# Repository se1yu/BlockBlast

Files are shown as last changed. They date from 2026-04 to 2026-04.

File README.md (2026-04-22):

# BlockBlast! 
- Demo Link: https://youtu.be/8z5zvf6NJ1U?si=ciNaijVOC2jGjhIF

Using knowledge from ECE 319H at UT Austin (Intro to Embedded Systems) to build a custom video game console and to program Block Blast from scratch. 

Block Blast is a puzzle game I implemented for a MSPM0G3507 microcontroller, displayed on a 128×160 ST7735 Liquid Crystal Display (LCD) screen. The player is presented with an 8×8 grid and a tray of three randomly selected blocks. Using a joystick and four external buttons, the player picks up blocks from the tray, moves them around the grid, and drops them into position. When an entire row or column of the grid becomes filled, it clears and the player earns points. The game ends when any remaining block in the tray has no valid position anywhere on the board. The game supports English and Spanish, tracks a persistent high score across rounds, and features four distinct sound effects triggered by gameplay events.
# Images






--------

# System Architecture
There are two ISRs running concurrently:
Armed with TimerG12_IntArm(80000000/30, 2), which fires an interrupt every 30ms. It does three things each tick:
- Calls JoyStick_In(&JoyX, &JoyY) — which internally triggers ADC_InDual (analog-to-digital-convertor) on ADC1 channels 4 and 6 (PB17 and PB19), sampling both joystick axes simultaneously via a dual-channel 12-bit ADC conversion. According to the Nyquist Theorem, an input should be sampled at a frequency at least twice the maximum input frequency. 30Hz (30 times a second) sampling is well above the maximum frequency a human wrist can move a joystick!
- Calls Switch_In() — reads the four external buttons wired to PA24–PA27, returning a 4-bit value where each bit represents one directional button that is currently being pressed (right/down/left/up). 
- Stores results in the global variables JoyX, JoyY, and sw_status for the main program to access these external hardware updates.

Regarding Audio, we have the SysTick_Handler — Audio DAC at 11 kHz:
Armed with SysTick_IntArm(80000000/11000, 0), this fires every ~90µs and drives the 5-bit binary-weighted DAC on PB0–PB4. It maintains three global variables: pointer to sound array(values to be played to output sound), arrayCount (total # of bytes per sound array), and arrayIndex (current position). Each tick it outputs pointer[arrayIndex] to DAC5_Out() and increments the index. When the array is exhausted it disables the interrupt. Sound is started by calling Sound_Start(pt, count) which resets the index and re-enables the interrupt. This ISR runs at higher priority (0) than the game timer (2) so audio never stutters during gameplay.

# ADC & Joystick
JoyStick_Init() calls ADC_InitDual(ADC1, 4, 6, ADCVREF_VDDA), configuring ADC1 to sequentially sample two channels in one software trigger: channel 4 (PB17, horizontal) and channel 6 (PB19, vertical). ADC_InDual triggers the conversion and "busy-waits" for both results, returning values 0–4095 for each axis. The neutral position is approximately 2048. In Game_Tick, the bounding numbers of 1000 and 3000 define deflection zones — below 1000 means pushed one way, above 3000 means the other. The joystick counts as two slide potentiometers sampled periodically by the ADC at 30 Hz inside the timer ISR.

# Switches/Buttons
Switch_Init() configures PA24–PA27 as digital inputs with PINCM = 0x40081 (input enable + pull-up). Switch_In() reads GPIOA->DIN31_0, masks bits 24–27, and right-shifts by 24 to produce a clean 4-bit value. These are four external buttons wired:
- Bit 0 = right (select / confirm)
- Bit 1 = down (place block)
- Bit 2 = left (back / cancel, requires ~1 second hold on game screen to go backwards)
- Bit 3 = up (pick up block / cancel pickup)

# Sound
Four gameplay sounds are defined in sounds.h as const uint8_t arrays of 5-bit DAC samples recorded at 11 kHz:
- Block_Pickup() — plays when the player picks up a block from the tray
- Block_Place() — plays on successful block placement
- Block_Reject() — plays when a drop is attempted in an invalid position
- Block_Clear() — plays when one or more rows or columns are cleared
Each calls Sound_Start(array, count) which loads the pointer/counter globals and enables the SysTick interrupt. The DAC is a 5-bit R-2R ladder on PB0–PB4, giving 32 voltage levels from 0 to 3.3V.

# Sprites & Graphics
All sprites I drew in Microsoft Paint are stored as const uint16_t arrays in images.h in RGB565 format (16 bit). ST7735_DrawBitmap(x, y, ptr, w, h) renders them with y as the bottom pixel edge. The active sprites in gameplay are:
- Home (128×160) — the menu/title screen background
- grid (128×160) — the full game screen including the 8×8 grid and tray area background
- single (12×12) — 1×1 cell
- miniwide (24×12) — 2×1 cells
- minitall (12×24) — 1×2 cells
- minisquare (24×24) — 2×2 cells
- wide (36×12) — 3×1 cells
- tall (12×36) — 1×3 cells
- square (36×36) — 3×3 cells
Moving sprite: The held block moves across the grid in 12px increments (one cell) responding to joystick deflection. On each move, ST7735_DrawBitmap(grid) redraws the background, all filled cells are repainted as solid 10×10px colored squares inside each 12×12 cell, the tray is redrawn, and finally the held block is drawn at its new position.

# Grid & Game Logic
The grid state is a uint8_t grid_matrix[8][8] where 0 = empty and 1 = filled. Block types are described by a BlockType_t struct containing the sprite pointer, pixel dimensions, and cell footprint. The active tray is traySlotType[3] — indices into allBlockTypes[7] — randomized each respawn using a linear congruential generator from SysTick->VAL at game start for true randomness. Random32() implements a linear congruential generator: M = 1664525*M + 1013904223. RandomType() uses (Random32() >> 24) % 7 — taking bits 31–24 for a cycle length of 2²⁴ rather than the short-cycling low bits. The seed M = SysTick->VAL is set once at Game_Init(), capturing the hardware counter at the moment the player starts the game, ensuring a different block sequence every round.

The canPlace(slot, col, row) checks bounds and scans the footprint against the matrix. stampBlock writes 1s into the matrix. checkAndClearLines() after every placement scans all 8 rows and 8 columns, marks full ones, then zeroes any cell whose row or column was full — handling intersections correctly without double-counting. isGameOver() iterates all available tray blocks and calls canBlockFitAnywhere() which scans every valid grid position; if any available block has zero valid placements, the game ends.

# LEDs 
Three LEDs on PA15–PA17 indicate which tray slot is currently selected. LED_On(data) left-shifts data by 15 to align with the GPIO pins. Only the LED corresponding to traySelection lights up, and it goes dark when that slot's block is picked up or placed.

# Language Support 
All user-facing strings exist in both English and Spanish. A lang variable (0 = English, 1 = Spanish) indexes into parallel string arrays for menu labels, tutorial text, and prompts. The language cycles with the Language menu option and persists through the game session.

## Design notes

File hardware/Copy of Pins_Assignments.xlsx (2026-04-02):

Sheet: Design
J1 | MSPM0 | MSPM0 | J3 | J4 | MSPM0 | MSPM0 | J2
 | 1 | 21 |  |  | 40 | 20
 | 3.3V | 5V |  | DAC5 | PB4[7] | GND
SWITCH | PA25 | GND |  | DAC5 | PB1[7] | PB12
PA9 or PB23 | SW1 | PB19 |  |  | PA28 | PB17
U1_Tx | PA8[4] | PA22[5] | U2_Rx |  | PA31 | PB15[1] | GPIO/Reset to ST7735
SWITCH | PA26 | PB18 | ADC1_5 Slide pot | TExaS scope ADC0_6 | PB20[6] | !RST
LED | PB24 | PA18 |  |  | PB13 | PB8[1] | MOSI to ST7735
SPI1_SCK | PB9[1] | PA24 | SWITCH | U0_TX [2] | PA10[3] | PB7[1] | MISO to ST7735
SWITCH | PA27 | PA17 | LED | U0_RX[2] | PA11[3] | PB6[1] | TFT_CS to ST7735
DAC5 | PB2[7] | SW2 | PA16 or PA18 (LED) | CARD_CS to ST7735 | PA12[1] | PB0[7] | DAC5
DAC5 | PB3[7] | PA15[0] | DAC output | D/C to ST7735 | PA13[1] | PB16
Notes: |  |  |  |  | MSPM0
[0] DAC output, but could be GPIO |  |  |  |  | DAC
[1] ST7735R LCD and SDC (either Adafruit and HiLetGo) with SDC |  |  |  |  | SPI1
[2] Slide pot to PB18 ADC1 channel 5 |  |  |  |  | ADC1
[3] UART0 communication with laptop, serial console window |  |  |  |  | UART0
[4] UART1 transmit output to other computer in Lab 8 |  |  |  |  | UART1
[5] UART2 receive input from other computer in Lab 8 |  |  |  |  | UART2
[6] ADC0 channel 6 analog input for TExaS scope, PB20 |  |  |  |  | ADC0
[7] 5 bit DAC |  |  |  |  | GPIOB
[8] MY LCD

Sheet: Timers
 | base clock | size | prescale
SysTick | 80MHz | 24 bit | none
TimerA0 | 80MHz | 16 bit | 8 bit
TimerA1 | 80MHz | 16 bit | 8 bit
TimerG0 | 40MHz | 16 bit | 8 bit
TimerG12 | 80MHz | 32 bit | none
TimerG6 | 80MHz | 16 bit | 8 bit
TimerG7 | 80MHz | 16 bit | 8 bit
TimerG8 | 40MHz | 16 bit | 8 bit

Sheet: Pins
notes | J5 pins
 | PA0 | PA.0/UART0_TX/I2C0_SDA/TIMA0_C0/TIMA1_FAL | J5 pins
 | PA1 | PA.1/UART0_RX/I2C0_SCL/TIMA0_C1/TIMA2_FAL | J5 pins
 | PA2 | PA.2/TIMG1_C1/SPI0_CS0/ROSC | J5 pins
 | PA3 | PA.3/TIMG1_C0/SPI0_CS1/UART2_CTS/TIMA0_C2/COMP1_OUT/LFXIN | J5 pins
 | PA4 | PA.4/TIMG1_C1/SPI0_POCI/UART2_RTS/TIMA0_C3/LFCLK_IN/LFXOUT | J5 pins
 | PA5 | PA.5/TIMG10_C0/SPI0_PICO/TIMA1_FAL/TIMG0_C0/HFXIN | J5 pins
 | PA6 | PA.6/TIMG10_C1/SPI0_SCK/TIMA0_FAL/TIMG0_C1/HFCLK_IN/ | J5 pins
 | PA7 | PA.7/COMP0_OUT/CLK_OUT/TIMG1_C0/TIMA0_C2/TIMG10_IDX | J5 pins
Duplicated on J4 | PA10 | PA.10/UART0_TX/SPI0_POCI/I2C0_SDA/TIMA1_C0/TIMH0_C0 | J5 pins
Duplicated on J4 | PA11 | PA.11/UART0_RX/SPI0_SCK/I2C0_SCL/TIMA1_C1/COMP0_OUT | J5 pins
Duplicated on J4 | PA12 | PA.12/UART3_CTS/SPI0_SCK/TIMG0_C0/CAN_TX | J5 pins
Duplicated on J4 | PA13 | PA.13/UART3_RTS/SPI0_POCI/UART3_RX/TIMG0_C1/CAN_RX/COMP0_IN2- | J5 pins
 | PA14 | PA.14/UART0_CTS/SPI0_PICO/UART3_TX/TIMH0_C0/CLK_OUT/COMP0_IN2+ | J5 pins
 | PA21 | PA.21/UART2_TX/TIMG10_C0/UART1_CTS/TIMA0_C0/ADC1_7/COMP2_IN1-/VeREF | J5 pins
 | PA23 | PA.23/UART2_TX/SPI0_CS3/TIMA2_C0/TIMG0_C0/UART3_CTS/COMP1_IN1-/VeREF+ | J5 pins
 | PB5 | PB.5/UART1_RX/UART3_RTS/TIMA1_C1 | J5 pins
 | PB10 | PB.10/TIMG0_C0/TIMG1_C0/COMP1_OUT | J5 pins
 | PB11 | PB.11/TIMG0_C1/TIMG1_C1/CLK_OUT | J5 pins
 | PB21 | PB.21/SPI1_POCI/TIMG10_C0/COMP2_IN0+ | J5 pins
 | PB22 | PB.22/SPI1_PICO/TIMG10_C1/COMP2_IN0- | J5 pins
J14 jumper to J1 | PB23 | PB.23/SPI1_SCK/COMP0_OUT/TIMA0_FAL | J5 pins
 | PB25 | PB.25/UART0_CTS/SPI0_CS0/TIMA2_FAL/ADC0_4 | J5 pins
 | PB26 | PB.26/UART0_RTS/SPI0_CS1/TIMA2_C0/COMP1_IN0+ | J5 pins
 | PB27 | PB.27/COMP2_OUT/SPI1_CS1/TIMA2_C1/COMP1_IN0- | J5 pins
QEI pins
 | PA29 | PA.29/I2C1_SCL/UART2_RTS/TIMG10_C0 | QEI pins
 | PA30 | PA.30/I2C1_SDA/UART2_CTS/TIMG10_C1 | QEI pins
 | PB14 | PB.14/SPI1_CS3/SPI1_POCI/SPI0_CS3/TIMH0_C1/TIMG10_IDX | QEI pins
 | J1
 | 3.3V
 | PA25 | PA.25/UART3_RX/SPI1_CS3/TIMH0_C1/TIMA0_C3/ADC0_2/OPA0_IN1+ | J1
 | PA9[5] | PA.9/UART1_RX/SPI0_PICO/UART0_CTS/TIMA0_C1/RTC | J1
 | PA8 | PA.8/UART1_TX/SPI0_CS0/UART0_RTS/TIMA0_C0 | J1
 | PB24 | PB.24/SPI0_CS3/SPI0_CS1/TIMA0_C3/TIMH0_C1/ADC0_5/COMP1_IN1+ | J1
 | PA26 | PA.26/UART3_TX/SPI1_CS0/TIMG1_C0/TIMA0_FAL/ADC0_1/COMP0_IN0+/OPA0_IN0+/GPAMP_IN+/CAN_TX | J1
 | PB9 | PB.9/UART1_RTS/SPI1_SCK/TIMA0_C1 | J1
 | PA27 | PA.27/RTC_OUT/SPI1_CS1/TIMG1_C1/TIMA2_FAL/ADC0_0/COMP0_IN0-/OPA0_IN0-/CAN_RX | J1
 | PB2 | PB.2/UART3_TX/UART2_CTS/I2C1_SCL/TIMA2_C0/UART1_CTS | J1
 | PB3 | PB.3/UART3_RX/UART2_RTS/I2C1_SDA/TIMA2_C1/UART1_RTS | J1
 | J3
 | 5V |  | J3
 | GND |  | J3
 | PB19 | PB.19/COMP2_OUT/SPI0_POCI/TIMG1_C1/UART0_CTS/ADC1_6/COMP2_IN1+/OPA1_IN0+ | J3
 | PA22 | PA.22/UART2_RX/TIMG10_C1/UART1_RTS/TIMA0_C1/CLK_OUT/ADC0_7/GPAMP_OUT/OPA0_OUT | J3
 | PB18 | PB.18/UART2_RX/SPI0_SCK/SPI1_CS2/TIMA1_C1/ADC1_5/COMP1_IN2+ | J3
 | PA18 | PA.18/UART1_RX/SPI1_PICO/I2C1_SDA/TIMA2_C1/BSL_invoke/ADC1_3/OPA1_IN1+/COMP0_IN1+/GPAMP_IN12 | J3
 | PA24 | PA.24/UART2_RX/SPI0_CS2/TIMA2_C1/TIMG0_C1/UART3_RTS/ADC0_3/OPA0_IN1- | J3
 | PA17 | PA.17/UART1_TX/SPI1_SCK/I2C1_SCL/TIMA2_C0/ADC1_2/OPA1_IN1-/COMP0_IN1- | J3
 | PA16[6] | PA.16/COMP2_OUT/SPI1_POCI/I2C1_SDA/TIMA1_C1/ADC1_1/OPA1_OUT | J3
 | PA15 | PA.15/UART0_RTS/SPI1_CS2/I2C1_SCL/TIMA1_C0/TIMG10_IDX/ADC1_0/DAC_OUT | J3
 | J4
 | PB4 | PB.4/UART1_TX/UART3_CTS/TIMA1_C0 | J4
 | PB1 | PB.1/UART0_RX/SPI1_CS3/TIMA1_C1 | J4
 | PA28 | PA.28/UART0_TX/I2C0_SDA/TIMA2_C0/TIMA0_FAL | J4
 | PA31 | PA.31/UART0_RX/I2C0_SCL/TIMA2_C1/TIMH0_C1/CLK_OUT | J4
 | PB20 | PB.20/SPI0_CS2/SPI1_CS0/TIMA0_C2/TIMH0_C0/TIMA1_FAL/ADC0_6/OPA1_IN0- | J4
 | PB13 | PB.13/UART3_RX/TIMA0_C3/TIMH0_C0 | J4
 | PA10 | PA.10/UART0_TX/SPI0_POCI/I2C0_SDA/TIMA1_C0/TIMH0_C0 | J4
 | PA11 | PA.11/UART0_RX/SPI0_SCK/I2C0_SCL/TIMA1_C1/COMP0_OUT | J4
 | PA12 | PA.12/UART3_CTS/SPI0_SCK/TIMG0_C0/CAN_TX | J4
 | PA13 | PA.13/UART3_RTS/SPI0_POCI/UART3_RX/TIMG0_C1/CAN_RX/COMP0_IN2- | J4
 | J2
 | GND |  | J2
 | PB12 | PB.12/UART3_TX/TIMA0_C2/TIMA1_FAL | J2
 | PB17 | PB.17/UART2_TX/SPI0_PICO/SPI1_CS1/TIMA1_C0/ADC1_4/COMP1_IN2- | J2
 | PB15 | PB.15/UART2_TX/SPI1_PICO/UART3_CTS/TIMG1_C0 | J2
 | !RST |  | J2
 | PB8 | PB.8/UART1_CTS/SPI1_PICO/TIMA0_C0/COMP1_OUT | J2
 | PB7 | PB.7/UART1_RX/SPI1_POCI/SPI0_CS2/TIMG10_C1/UART2_RTS | J2
 | PB6 | PB.6/UART1_TX/SPI1_CS0/SPI0_CS1/TIMG10_C0/UART2_CTS | J2
 | PB0 | PB.0/UART0_TX/SPI1_CS2/TIMA1_C0 | J2
 | PB16 | PB.16/UART2_RX/SPI1_SCK/UART3_RTS/TIMG1_C1 | J2

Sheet: J5
M0G350 Header | A0 | B25 | B22 | B11 | B5 | A1 | A14 | A6 | A4 | A2 | GND | GND | A11
M0G350 Header | B27 | B26 | B23 | B21 | B10 | A23 | A21 | A7 | A5 | A3 | A12 | A13 | A10

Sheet: PINCM
PINCM | Pin | Mode2 | Mode3 | Mode4 | Mode5 | Mode6 | Mode7 | Mode8 | Mode9
1 | PA0 | UART0_TX | I2C0_SDA | TIMA0_C0 | TIMA_FAL1 | TIMG8_C1 | FCC_IN
2 | PA1 | UART0_RX | I2C0_SCL | TIMA0_C1 | TIMA_FAL2 | TIMG8_IDX | TIMG8_C0
7 | PA2 | TIMG8_C1 | SPI0_CS0 | TIMG7_C1 | SPI1_CS0
8 | PA3 | TIMG8_C0 | SPI0_CS1 | UART2_CTS | TIMA0_C2 | COMP1_OUT | TIMG7_C0 | TIMA0_C1 | I2C1_SDA
9 | PA4 | TIMG8_C1 | SPI0_POCI | UART2_RTS | TIMA0_C3 | LFCLK_IN | TIMG7_C1 | TIMA0_C1N | I2C1_SCL
10 | PA5 | TIMG8_C0 | SPI0_PICO | TIMA_FAL1 | TIMG0_C0 | TIMG6_C0 | FCC_IN
11 | PA6 | TIMG8_C1 | SPI0_SCK | TIMA_FAL0 | TIMG0_C1 | HFCLK_IN | TIMG6_C1 | TIMA0_C2N
14 | PA7 | COMP0_OUT | CLK_OUT | TIMG8_C0 | TIMA0_C2 | TIMG8_IDX | TIMG7_C1 | TIMA0_C1
19 | PA8 | UART1_TX | SPI0_CS0 | UART0_RTS | TIMA0_C0 | TIMA1_C0N
20 | PA9 | UART1_RX | SPI0_PICO | UART0_CTS | TIMA0_C1 | RTC_OUT | TIMA0_C0N | TIMA1_C1N | CLK_OUT
21 | PA10 | UART0_TX | SPI0_POCI | I2C0_SDA | TIMA1_C0 | TIMG12_C0 | TIMA0_C2 | I2C1_SDA | CLK_OUT
22 | PA11 | UART0_RX | SPI0_SCK | I2C0_SCL | TIMA1_C1 | COMP0_OUT | TIMA0_C2N | I2C1_SCL
34 | PA12 | UART3_CTS | SPI0_SCK | TIMG0_C0 | CAN_TX | TIMA0_C3 | FCC_IN
35 | PA13 | UART3_RTS | SPI0_POCI | UART3_RX | TIMG0_C1 | CAN_RX | TIMA0_C3N
36 | PA14 | UART0_CTS | SPI0_PICO | UART3_TX | TIMG12_C0 | CLK_OUT
37 | PA15 | UART0_RTS | SPI1_CS2 | I2C1_SCL | TIMA1_C0 | TIMG8_IDX | TIMA1_C0N | TIMA0_C2
38 | PA16 | COMP2_OUT | SPI1_POCI | I2C1_SDA | TIMA1_C1 | TIMA1_C1N | TIMA0_C2N | FCC_IN
39 | PA17 | UART1_TX | SPI1_SCK | I2C1_SCL | TIMA0_C3 | TIMG7_C0 | TIMA1_C0
40 | PA18 | UART1_RX | SPI1_PICO | I2C1_SDA | TIMA0_C3N | TIMG7_C1 | TIMA1_C1
41 | PA19 | SWDIO
42 | PA20 | SWCLK
46 | PA21 | UART2_TX | TIMG8_C0 | UART1_CTS | TIMA0_C0 | TIMG6_C0
47 | PA22 | UART2_RX | TIMG8_C1 | UART1_RTS | TIMA0_C1 | CLK_OUT | TIMA0_C0N | TIMG6_C1
53 | PA23 | UART2_TX | SPI0_CS3 | TIMA0_C3 | TIMG0_C0 | UART3_CTS | TIMG7_C0 | TIMG8_C0
54 | PA24 | UART2_RX | SPI0_CS2 | TIMA0_C3N | TIMG0_C1 | UART3_RTS | TIMG7_C1 | TIMA1_C1
55 | PA25 | UART3_RX | SPI1_CS3 | TIMG12_C1 | TIMA0_C3 | TIMA0_C1N
59 | PA26 | UART3_TX | SPI1_CS0 | TIMG8_C0 | TIMA_FAL0 | CAN_TX | TIMG7_C0
60 | PA27 | RTC_OUT | SPI1_CS1 | TIMG8_C1 | TIMA_FAL2 | CAN_RX | TIMG7_C1
3 | PA28 | UART0_TX | I2C0_SDA | TIMA0_C3 | TIMA_FAL0 | TIMG7_C0 | TIMA1_C0
4 | PA29 | I2C1_SCL | UART2_RTS | TIMG8_C0 | TIMG6_C0
5 | PA30 | I2C1_SDA | UART2_CTS | TIMG8_C1 | TIMG6_C1
6 | PA31 | UART0_RX | I2C0_SCL | TIMA0_C3N | TIMG12_C1 | CLK_OUT | TIMG7_C1 | TIMA1_C1
12 | PB0 | UART0_TX | SPI1_CS2 | TIMA1_C0 | TIMA0_C2
13 | PB1 | UART0_RX | SPI1_CS3 | TIMA1_C1 | TIMA0_C2N
15 | PB2 | UART3_TX | UART2_CTS | I2C1_SCL | TIMA0_C3 | UART1_CTS | TIMG6_C0 | TIMA1_C0
16 | PB3 | UART3_RX | UART2_RTS | I2C1_SDA | TIMA0_C3N | UART1_RTS | TIMG6_C1 | TIMA1_C1
17 | PB4 | UART1_TX | UART3_CTS | TIMA1_C0 | TIMA0_C2 | TIMA1_C0N
18 | PB5 | UART1_RX | UART3_RTS | TIMA1_C1 | TIMA0_C2N | TIMA1_C1N
23 | PB6 | UART1_TX | SPI1_CS0 | SPI0_CS1 | TIMG8_C0 | UART2_CTS | TIMG6_C0 | TIMA1_C0N
24 | PB7 | UART1_RX | SPI1_POCI | SPI0_CS2 | TIMG8_C1 | UART2_RTS | TIMG6_C1 | TIMA1_C1N
25 | PB8 | UART1_CTS | SPI1_PICO | TIMA0_C0 | COMP1_OUT
26 | PB9 | UART1_RTS | SPI1_SCK | TIMA0_C1 | TIMA0_C0N
27 | PB10 | TIMG0_C0 | TIMG8_C0 | COMP1_OUT | TIMG6_C0
28 | PB11 | TIMG0_C1 | TIMG8_C1 | CLK_OUT | TIMG6_C1
29 | PB12 | UART3_TX | TIMA0_C2 | TIMA_FAL1 | TIMA0_C1
30 | PB13 | UART3_RX | TIMA0_C3 | TIMG12_C0 | TIMA0_C1N
31 | PB14 | SPI1_CS3 | SPI1_POCI | SPI0_CS3 | TIMG12_C1 | TIMG8_IDX | TIMA0_C0
32 | PB15 | UART2_TX | SPI1_PICO | UART3_CTS | TIMG8_C0 | TIMG7_C0
33 | PB16 | UART2_RX | SPI1_SCK | UART3_RTS | TIMG8_C1 | TIMG7_C1
43 | PB17 | UART2_TX | SPI0_PICO | SPI1_CS1 | TIMA1_C0 | TIMA0_C2
44 | PB18 | UART2_RX | SPI0_SCK | SPI1_CS2 | TIMA1_C1 | TIMA0_C2N
45 | PB19 | COMP2_OUT | SPI0_POCI | TIMG8_C1 | UART0_CTS | TIMG7_C1
48 | PB20 | SPI0_CS2 | SPI1_CS0 | TIMA0_C2 | TIMG12_C0 | TIMA_FAL1 | TIMA0_C1 | TIMA1_C1N
49 | PB21 | SPI1_POCI | TIMG8_C0
50 | PB22 | SPI1_PICO | TIMG8_C1
51 | PB23 | SPI1_SCK | COMP0_OUT | TIMA_FAL0
52 | PB24 | SPI0_CS3 | SPI0_CS1 | TIMA0_C3 | TIMG12_C1 | TIMA0_C1N | TIMA1_C0N
56 | PB25 | UART0_CTS | SPI0_CS0 | TIMA_FAL2
57 | PB26 | UART0_RTS | SPI0_CS1 | TIMA0_C3 | TIMG6_C0 | TIMA1_C0
58 | PB27 | COMP2_OUT | SPI1_CS1 | TIMA0_C3N | TIMG6_C1 | TIMA1_C1

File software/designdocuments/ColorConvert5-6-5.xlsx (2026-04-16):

red | green | blue | 565
0 | 255 | 120 | 0x7FE0 | 0x7FE0, // 0, 255, 120

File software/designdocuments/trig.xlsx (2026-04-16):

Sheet: 64
 | 2 |  | 64
angle | vx | vy | ix | iy
0 | 2 | 0 | 128 | 0
0.09817477042 | 1.990369453 | 0.1960342807 | 127 | 13
0.1963495408 | 1.961570561 | 0.390180644 | 126 | 25
0.2945243113 | 1.913880671 | 0.5805693545 | 122 | 37
0.3926990817 | 1.847759065 | 0.7653668647 | 118 | 49
0.4908738521 | 1.763842529 | 0.9427934737 | 113 | 60
0.5890486225 | 1.662939225 | 1.111140466 | 106 | 71
0.687223393 | 1.546020907 | 1.268786568 | 99 | 81
0.7853981634 | 1.414213562 | 1.414213562 | 91 | 91
0.8835729338 | 1.268786568 | 1.546020907 | 81 | 99
0.9817477042 | 1.111140466 | 1.662939225 | 71 | 106
1.079922475 | 0.9427934737 | 1.763842529 | 60 | 113
1.178097245 | 0.7653668647 | 1.847759065 | 49 | 118
1.276272016 | 0.5805693545 | 1.913880671 | 37 | 122
1.374446786 | 0.390180644 | 1.961570561 | 25 | 126
1.472621556 | 0.1960342807 | 1.990369453 | 13 | 127
1.570796327 | -7.656635742e-16 | 2 | 0 | 128
1.668971097 | -0.1960342807 | 1.990369453 | -13 | 127
1.767145868 | -0.390180644 | 1.961570561 | -25 | 126
1.865320638 | -0.5805693545 | 1.913880671 | -37 | 122
1.963495408 | -0.7653668647 | 1.847759065 | -49 | 118
2.061670179 | -0.9427934737 | 1.763842529 | -60 | 113
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

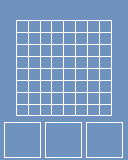
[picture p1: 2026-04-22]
software/images/Blocks/grid.bmp

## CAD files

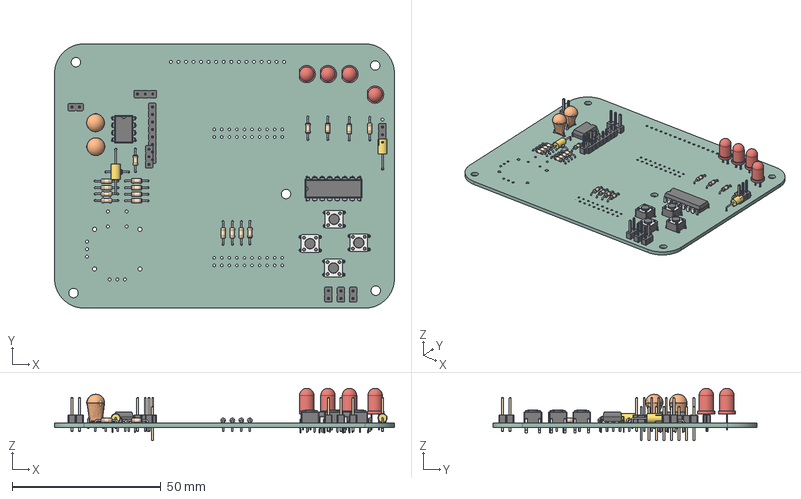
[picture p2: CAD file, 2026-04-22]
hardware/v1.0.0/model.step
114.3 x 88.9 x 17.6 mm
R_Axial_DIN0204_L3.6mm_D1.6mm_P7.62mm_Horizontal x 18
PinHeader_1x03_P2.54mm_Vertical x 3
DIP-8_W7.62mm
SW_PUSH_6mm x 4
PinHeader_1x02_P2.54mm_Vertical x 4
C_Axial_L5.1mm_D3.1mm_P15.00mm_Horizontal x 2
PinHeader_1x08_P2.54mm_Vertical
CP_Radial_Tantal_D6.0mm_P5.00mm x 2
DIP-16_W7.62mm
LED_D5.0mm x 4
jc224364_PCB

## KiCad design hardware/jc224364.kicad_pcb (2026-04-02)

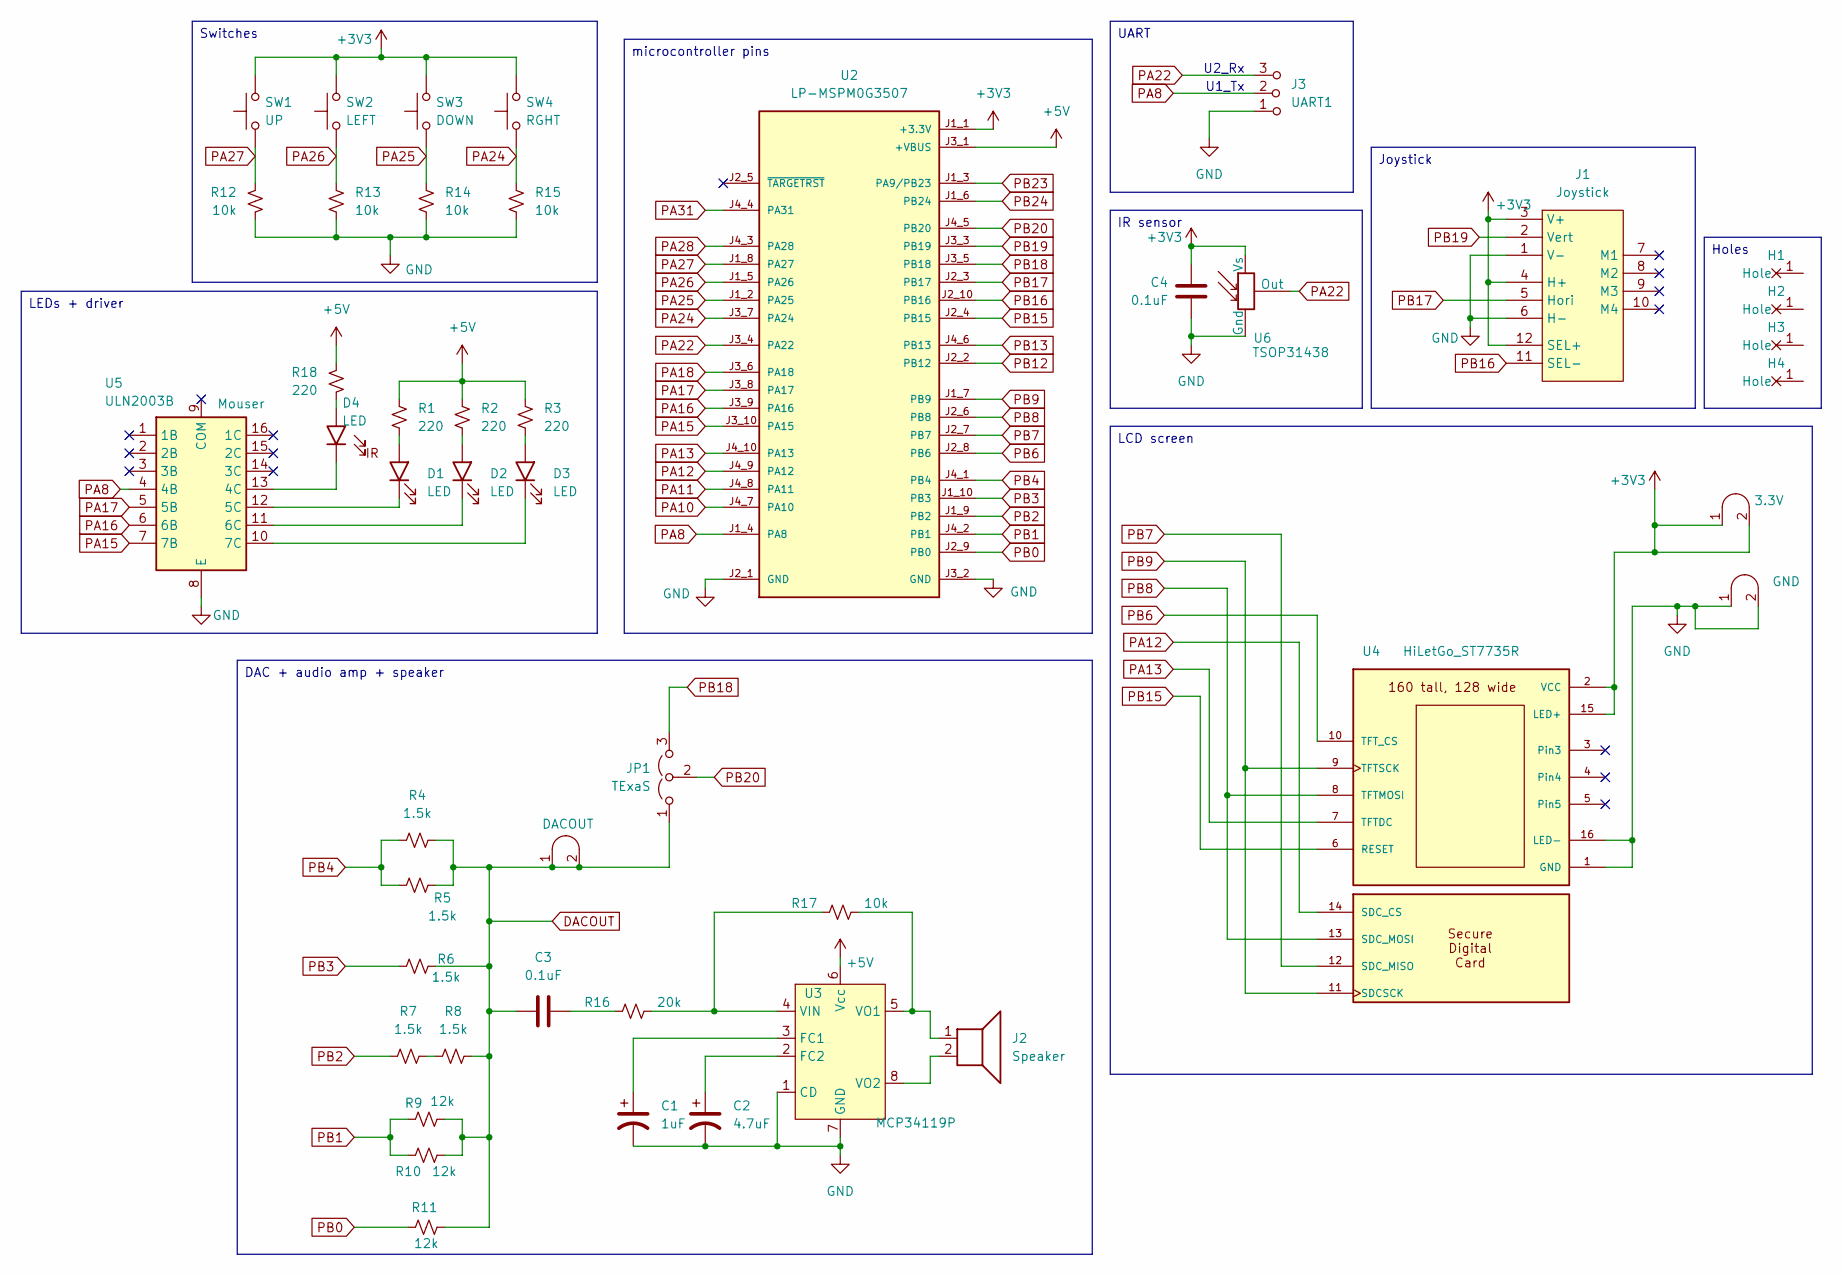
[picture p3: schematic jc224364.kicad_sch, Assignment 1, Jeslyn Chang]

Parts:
C1: 1uF; CP_Radial_Tantal200mil
C2: 4.7uF; CP_Radial_Tantal200mil
C3, C4: 0.1uF; C_Axial_200mil
D1, D2, D3, D4: LED; LED_D5.0mm
H1, H2, H3, H4: MountingHole_4_40
J1: Joystick; SparkfunJoystick
J2: Speaker; PinHeader_1x02_P2.54mm_Vertical
J3: UART1; PinHeader_1x03_P2.54mm_Vertical
J6: GND; Testpoint_1x02_P2.54mm
J7: DACOUT; Testpoint_1x02_P2.54mm
JP1: TExaS; PinHeader_1x03_P2.54mm_Vertical
R1, R2, R3, R18: 220; R_Axial_DIN0204_L3.6mm_D1.6mm_P7.62mm_Horizontal
R4, R5, R6, R7, R8: 1.5k; R_Axial_DIN0204_L3.6mm_D1.6mm_P7.62mm_Horizontal
R9, R10, R11: 12k; R_Axial_DIN0204_L3.6mm_D1.6mm_P7.62mm_Horizontal
R12, R13, R14, R15, R17: 10k; R_Axial_DIN0204_L3.6mm_D1.6mm_P7.62mm_Horizontal
R16: 20k; R_Axial_DIN0204_L3.6mm_D1.6mm_P7.62mm_Horizontal
SW1: UP; SW_PUSH_6mm
SW2: LEFT; SW_PUSH_6mm
SW3: DOWN; SW_PUSH_6mm
SW4: RGHT; SW_PUSH_6mm
TP1: 3.3V; Testpoint_1x02_P2.54mm
U2: LP-MSPM0G3507; ti_LP_MSPM0G3507
U3: MCP34119P; DIP-8_W7.62mm_LongPads
U4: HiLetGo_ST7735R; hiletgo_st7735r
U5: ULN2003B; DIP-16_W7.62mm
U6: TSOP31438

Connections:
+3V3: C4.1, J1.3 (V+), J1.4 (H+), J1.12 (SEL+), SW1.2, SW2.2, SW3.2, SW4.2, TP1.1 (A), TP1.2 (B), U2.J1_1 (+3.3V), U4.2 (VCC), U4.15 (LED+), U6.2 (Vs)
+5V: R1.1, R2.1, R3.1, R18.1, U2.J3_1 (+VBUS), U3.6 (Vcc)
DACOUT: C3.1, J7.1 (A), J7.2 (B), JP1.1 (A), R4.1, R5.1, R6.1, R8.1, R9.1, R10.1, R11.1
GND: C1.2, C2.2, C4.2, J1.1 (V-), J1.6 (H-), J3.1 (A), J6.1 (A), J6.2 (B), R12.2, R13.2, R14.2, R15.2, U2.J2_1 (GND), U2.J3_2 (GND), U3.1 (CD), U3.7 (GND), U4.1 (GND), U4.16 (LED-), U5.8 (E), U6.1 (Gnd)
unnamed: C3.2, R16.2
unnamed: D1.2 (A), R1.2
unnamed: D1.1 (K), U5.12 (5C)
unnamed: D2.2 (A), R2.2
unnamed: D2.1 (K), U5.11 (6C)
unnamed: D3.2 (A), R3.2
unnamed: D3.1 (K), U5.10 (7C)
unnamed: D4.2 (A), R18.2
unnamed: D4.1 (K), U5.13 (4C)
unnamed: R7.1, R8.2
unnamed: C1.1, U3.3 (FC1)
unnamed: C2.1, U3.2 (FC2)
unnamed: R16.1, R17.2, U3.4 (VIN)
unnamed: J2.1, R17.1, U3.5 (VO1)
unnamed: J2.2, U3.8 (VO2)
PA8: J3.2 (B), U2.J1_4 (PA8), U5.4 (4B)
PA10: U2.J4_7 (PA10)
PA11: U2.J4_8 (PA11)
PA12: U2.J4_9 (PA12), U4.14 (SDC_CS)
PA13: U2.J4_10 (PA13), U4.7 (TFTDC)
PA15: U2.J3_10 (PA15), U5.7 (7B)
PA16: U2.J3_9 (PA16), U5.6 (6B)
PA17: U2.J3_8 (PA17), U5.5 (5B)
PA18: U2.J3_6 (PA18)
PA22: J3.3 (C), U2.J3_4 (PA22), U6.3 (Out)
PA24: R15.1, SW4.1, U2.J3_7 (PA24)
PA25: R14.1, SW3.1, U2.J1_2 (PA25)
PA26: R13.1, SW2.1, U2.J1_5 (PA26)
PA27: R12.1, SW1.1, U2.J1_8 (PA27)
PA28: U2.J4_3 (PA28)
PA31: U2.J4_4 (PA31)
PB0: R11.2, U2.J2_9 (PB0)
PB1: R9.2, R10.2, U2.J4_2 (PB1)
PB2: R7.2, U2.J1_9 (PB2)
PB3: R6.2, U2.J1_10 (PB3)
PB4: R4.2, R5.2, U2.J4_1 (PB4)
PB6: U2.J2_8 (PB6), U4.10 (TFT_CS)
PB7: U2.J2_7 (PB7), U4.12 (SDC_MISO)
PB8: U2.J2_6 (PB8), U4.8 (TFTMOSI), U4.13 (SDC_MOSI)
PB9: U2.J1_7 (PB9), U4.9 (TFTSCK), U4.11 (SDCSCK)
PB12: U2.J2_2 (PB12)
PB13: U2.J4_6 (PB13)
PB15: U2.J2_4 (PB15), U4.6 (RESET)
PB16: J1.11 (SEL-), U2.J2_10 (PB16)
PB17: J1.5 (Hori), U2.J2_3 (PB17)
PB18: JP1.3 (B), U2.J3_5 (PB18)
PB19: J1.2 (Vert), U2.J3_3 (PB19)
PB20: JP1.2 (C), U2.J4_5 (PB20)
PB23: U2.J1_3 (PA9/PB23)
PB24: U2.J1_6 (PB24)

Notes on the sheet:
U2_Rx
U1_Tx
Joystick
Holes
LEDs + driver
IR sensor
microcontroller pins
LCD screen
DAC + audio amp + speaker
Switches
UART

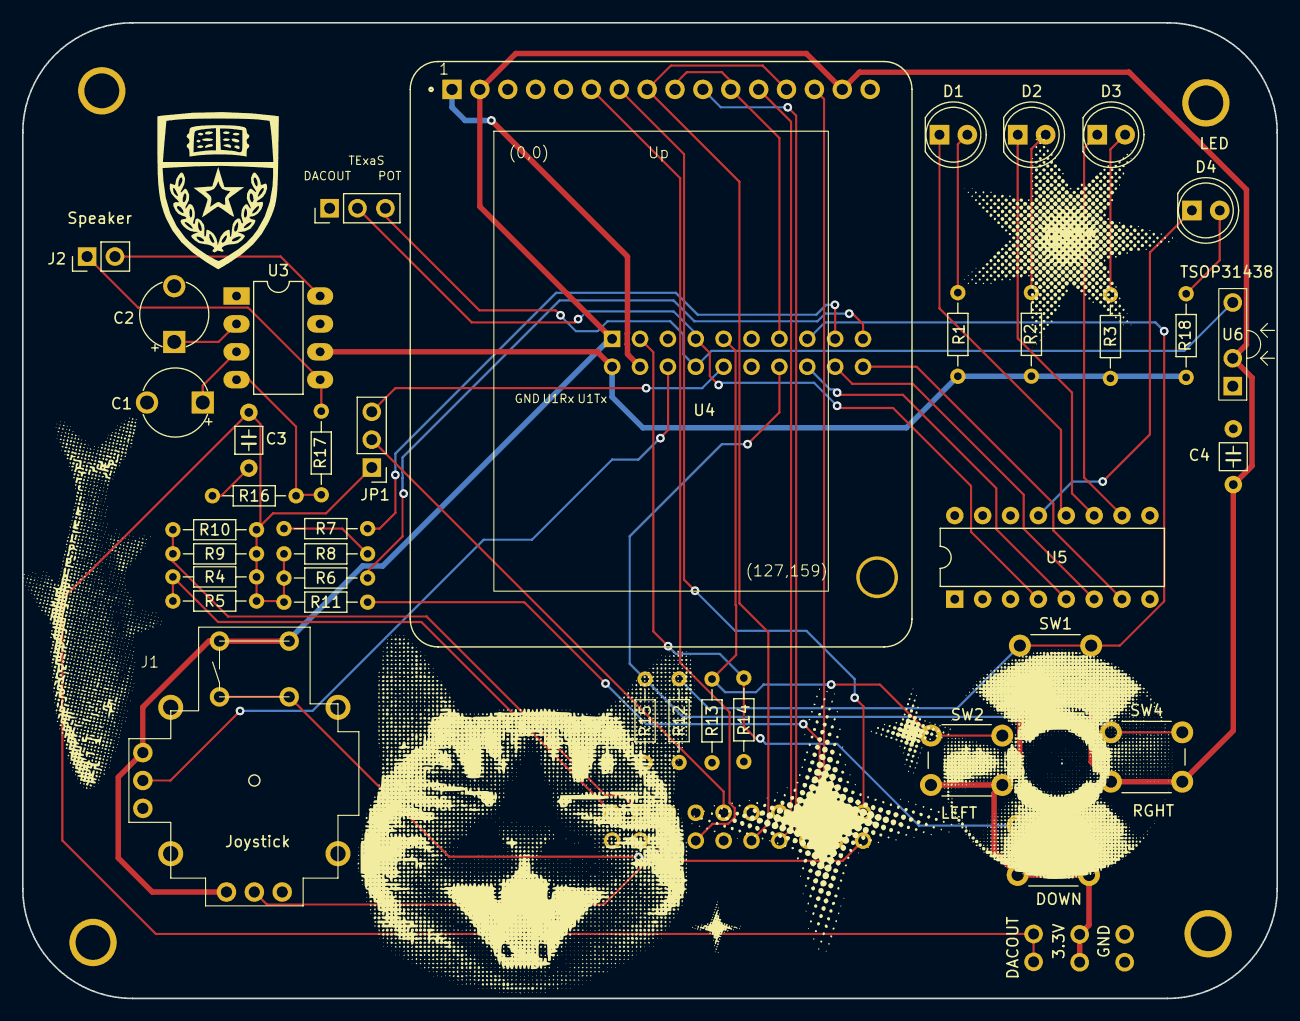
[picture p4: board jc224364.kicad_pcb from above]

Board: 2 copper layers, 114.3 x 88.9 mm, 46 parts (1 on the bottom side), 45 nets.

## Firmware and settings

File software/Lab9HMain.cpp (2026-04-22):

// Lab9HMain.cpp
// Runs on MSPM0G3507
// Lab 9 ECE319H
// Jeslyn Chang + Saaketh Manepalli
// Last Modified: 4/21/2026

#include <stdio.h>
#include <stdint.h>
#include <ti/devices/msp/msp.h>
#include "../inc/ST7735.h"
#include "../inc/Clock.h"
#include "../inc/LaunchPad.h"
#include "../inc/TExaS.h"
#include "../inc/Timer.h"
//#include "../inc/SlidePot.h"
#include "../inc/DAC5.h"
#include "SmallFont.h"
#include "LED.h"
#include "Switch.h"
#include "Sound.h"
#include "images\images.h"
extern "C" {
  #include "JoyStick.h"
}

typedef enum {MENU, TUTORIAL, LANG, GAME, SPN_MENU, SPN_TUTORIAL, SPN_LANG, SPN_GAME} GameState_t;
GameState_t state = MENU;

#define LED_MASK ((1<<17)|(1<<16)|(1<<15))

extern "C" void __disable_irq(void);
extern "C" void __enable_irq(void);
extern "C" void TIMG12_IRQHandler(void);
//globals
uint32_t JoyX, JoyY;
uint32_t sw_status;

//   Grid pixel origin:  top-left  = (16, 20)
//    bottom-right = (111, 115)  (8 cols x 8 rows x 12px)
//   Cell size: 12px
//   Grid cells: 8 columns (0-7), 8 rows (0-7)
//
//   ST7735_DrawBitmap(x, y, ptr, w, h)
//     x = left pixel, y = BOTTOM pixel  (ST7735 convention)
//
//   Switch bits (Switch_In() return):
//     bit 0 = right 
//     bit 1 = down
//     bit 2 = left (the main back button)
//     bit 3 = up
//   LED_On(mask). LED_On will shift the bits left to match leds pin 
//   LED_MASK = (1<<17)|(1<<16)|(1<<15)
//   Left LED  = 1<<15, Middle LED = 1<<16, Right LED = 1<<17

//constants
#define GRID_X0 16    // left pixel of grid
#define GRID_Y0 20    // top pixel of grid
#define CELL_SIZE 12    // pixels per cell
#define GRID_COLS 8
#define GRID_ROWS 8

// Switch bit masking
#define SWITCH_UP      0x08  // bit 3
#define SWITCH_DOWN    0x02  // bit 1
#define SWITCH_RIGHT   0x01  // bit 0 (select block in tray)
#define SWITCH_LEFT    0x04  // bit 2 (select block in tray, or back)

// LED masks for each tray slot (left=slot0, mid=slot1, right=slot2)
#define LED_SLOT2  (1<<0)
#define LED_SLOT1  (1<<1)
#define LED_SLOT0  (1<<2)

// score
uint32_t score;  // total cells cleared
uint32_t highScore = 0;

//block definitions
// all blocks are listed by its footprint in cells (cols x rows)
// and its sprite dimensions in pixels
typedef struct {
  const uint16_t *sprite;
  uint8_t spW; // sprite pixel width
  uint8_t spH; // sprite pixel height
  uint8_t cellCols; //footprint columns
  uint8_t cellRows; // footprint rows
} BlockType_t;

// All possible block types (7 total)
#define NUM_BLOCK_TYPES 7
const BlockType_t allBlockTypes[NUM_BLOCK_TYPES] = {
  {single, 12, 12, 1, 1 }, // 1x1
  {miniwide, 24, 12, 2, 1 },//2x1
  {minitall, 12, 24, 1, 2 },// 1x2
  {minisquare, 24, 24, 2, 2 },// 2x2
  {wide, 36, 12, 3, 1 },//3x1
  {tall, 12, 36, 1, 3 },// 1x3
  {square, 36, 36, 3, 3 },// 3x3
};

// Active tray: which type index is in each of the 3 slots
uint8_t traySlotType[3]; // index into allBlockTypes

// Tray draw positions (x=left pixel, y=bottom pixel for DrawBitmap)
const uint8_t trayX[3] = {4, 44, 86};
const uint8_t trayY[3] = {157, 157,157};

//game status variables
// establish the 2X2 array for grid tracking
//thank you omar for the guidance :D
uint8_t grid_matrix[GRID_ROWS][GRID_COLS]; // 0=empty, 1=filled
uint8_t blockAvail[3];// 1=available in tray, 0=already placed

uint8_t traySelection;// 0,1,2 - which tray slot cursor is on
uint8_t holding; // 1 = player has picked up a block
uint8_t holdSlot; // which block type (0,1,2) is being held

//held block position in grid cells (top-left cell of footprint)
int8_t holdCol; // can be -1 if partially off grid (badpixel alignment)
int8_t holdRow;

// Debounce flags for buttons (in addition to existing lastBtn/lastJoy)
uint8_t lastUpBtn;
uint8_t lastDownBtn;
uint8_t lastJoyX;// for left/right joystick (tray selection)

//RNG SETUP
uint32_t M=1;
uint32_t Random32(void){
  M = 1664525*M+1013904223;
  return M;
}
uint32_t Random(uint32_t n){
  return (Random32()>>16)%n;
}

//converting grid -> screen pixel
static inline uint8_t cellToPixX(int8_t col){ return GRID_X0 + col * CELL_SIZE; }
static inline uint8_t cellToPixY(int8_t row){ return GRID_Y0 + row * CELL_SIZE; }

//does it fit in (col, row)?
static uint8_t canPlace(uint8_t slot, int8_t col, int8_t row){
  uint8_t cc = allBlockTypes[traySlotType[slot]].cellCols;
  uint8_t cr = allBlockTypes[traySlotType[slot]].cellRows;
  if (col < 0 || row < 0) return 0;
  if (col + cc > GRID_COLS) return 0;
  if (row + cr > GRID_ROWS) return 0;
  for (uint8_t r = 0; r < cr; r++){
    for (uint8_t c = 0; c < cc; c++){
      if (grid_matrix[row + r][col + c]) return 0;
    }
  }
  return 1;
}

// place block into the grid
static void stampBlock(uint8_t slot, int8_t col, int8_t row){
  uint8_t cc = allBlockTypes[traySlotType[slot]].cellCols;
  uint8_t cr = allBlockTypes[traySlotType[slot]].cellRows;
  for (uint8_t r = 0; r < cr; r++){
    for (uint8_t c = 0; c < cc; c++){
      grid_matrix[row + r][col + c] = 1;
    }
  }
}

//update LEDs to correspond to current selected block.
// Only one LED on at a time; if a slot is empty it stays off
static void updateLEDs(void){
  uint32_t mask = 0;
  if (traySelection == 0 && blockAvail[0]) mask = LED_SLOT0;
  if (traySelection == 1 && blockAvail[1]) mask = LED_SLOT1;
  if (traySelection == 2 && blockAvail[2]) mask = LED_SLOT2;
  LED_Off(LED_MASK);
  if (mask) LED_On(mask);
}

// redrawing the bottom tray (when dirtyFlag = 1)
static void drawTray(void){
  for (uint8_t i = 0; i < 3; i++){
    if (blockAvail[i]){
      ST7735_DrawBitmap(trayX[i], trayY[i],
      allBlockTypes[traySlotType[i]].sprite,
      allBlockTypes[traySlotType[i]].spW,
      allBlockTypes[traySlotType[i]].spH);
    }
  }
}

//draw held block at its current pixel position 
// pixX/pixY = top-left pixel
static void drawHeldBlock(int16_t pixX, int16_t pixY, uint8_t erase){
  uint16_t color = erase ? ST7735_BLACK : 0; // 0 = draw normally via sprite
  if (!erase){
    // DrawBitmap takes x=left, y=bottom
    ST7735_DrawBitmap((int16_t)pixX,
    (int16_t)(pixY + allBlockTypes[traySlotType[holdSlot]].spH - 1),
    allBlockTypes[traySlotType[holdSlot]].sprite,
    allBlockTypes[traySlotType[holdSlot]].spW,
    allBlockTypes[traySlotType[holdSlot]].spH);
  }
  else{
    for (uint8_t r = 0; r < allBlockTypes[traySlotType[holdSlot]].spH; r++){
      for (uint8_t c = 0; c < allBlockTypes[traySlotType[holdSlot]].spW; c++){
        ST7735_DrawPixel(pixX + c, pixY + r, ST7735_BLACK);
      }
    }
  }
}

//score UI 
static void drawScore(void) {
  ST7735_DrawString(0, 0, (char *)"Pts:", ST7735_CYAN);
  ST7735_SetTextColor(ST7735_WHITE);
  ST7735_SetCursor(4, 0);
  ST7735_OutUDec(score);
  ST7735_OutString((char *)"  ");
  ST7735_DrawString(11, 0, (char *)"HI:", ST7735_CYAN);
  ST7735_SetTextColor(ST7735_WHITE);
  ST7735_SetCursor(14, 0);
  ST7735_OutUDec(highScore);
  ST7735_OutString((char *)"    ");
}

//clearing a row/col
static void checkAndClearLines(void){
  uint8_t fullRow[GRID_ROWS] = {0};
  uint8_t fullCol[GRID_COLS] = {0};
  uint8_t anyCleared = 0;

  for (uint8_t r = 0; r < GRID_ROWS; r++){
    uint8_t full = 1;
    for (uint8_t c = 0; c < GRID_COLS; c++)
    if (!grid_matrix[r][c]){ full = 0; break; }
    fullRow[r] = full;
    if (full) anyCleared = 1;
  }
  for (uint8_t c = 0; c < GRID_COLS; c++){
    uint8_t full = 1;
    for (uint8_t r = 0; r < GRID_ROWS; r++)
    if (!grid_matrix[r][c]){ full = 0; break; }
    fullCol[c] = full;
    if (full) anyCleared = 1;
  }

  if (!anyCleared) return;

  uint8_t cellsCleared = 0;
  for (uint8_t r = 0; r < GRID_ROWS; r++)
  for (uint8_t c = 0; c < GRID_COLS; c++)
  if ((fullRow[r] || fullCol[c]) && grid_matrix[r][c]){
    grid_matrix[r][c] = 0;
    cellsCleared++;
  }
  score += cellsCleared;
  Block_Clear();
}

// returns 1 if the given slot can fit anywhere on the current grid
static uint8_t canBlockFitAnywhere(uint8_t slot){
  uint8_t maxCol = GRID_COLS - allBlockTypes[traySlotType[slot]].cellCols;
  uint8_t maxRow = GRID_ROWS - allBlockTypes[traySlotType[slot]].cellRows;
  for (uint8_t r = 0; r <= maxRow; r++)
  for (uint8_t c = 0; c <= maxCol; c++)
  if (canPlace(slot, c, r)) return 1;
  return 0;
}

// returns 1 if no available block in the tray can fit anywhere—> game will b over
static uint8_t isGameOver(void){
  for (uint8_t i = 0; i < 3; i++)
  if (blockAvail[i] && !canBlockFitAnywhere(i)) return 1;
  return 0;
}

//GAME over UI 
static void showGameOver(void) {
  if (score > highScore) highScore = score;
  Clock_Delay1ms(2000);
  ST7735_FillScreen(ST7735_BLACK);
  ST7735_DrawString(2, 2, (char *)"GAME OVER", ST7735_RED);
  // Divider line
  ST7735_DrawFastHLine(0, 32, 128, ST7735_RED);

  // Score in white
  ST7735_DrawString(1, 4, (char *)"Score:", ST7735_CYAN);
  ST7735_SetTextColor(ST7735_WHITE);
  ST7735_SetCursor(7, 4);
  ST7735_OutUDec(score);

  // High score in yellow
  ST7735_DrawString(1, 6, (char *)"Best: ", ST7735_CYAN);
  ST7735_SetTextColor(ST7735_YELLOW);
  ST7735_SetCursor(7, 6);
  ST7735_OutUDec(highScore);

  // Prompt in grey
  ST7735_DrawFastHLine(0, 90, 128, ST7735_WHITE);
  ST7735_DrawString(0, 10, (char *)"Press right btn", ST7735_WHITE);
  ST7735_DrawString(1, 11, (char *)"to play again", ST7735_WHITE);
}

static uint8_t RandomType(void){
  return (uint8_t)((Random32() >> 24) % NUM_BLOCK_TYPES);
}

static void respawnTray(void){
  traySlotType[0] = RandomType();
  traySlotType[1] = RandomType();
  traySlotType[2] = RandomType();
  blockAvail[0] = blockAvail[1] = blockAvail[2] = 1;
  traySelection = 0;
}
// call game_init when entering a game state
static void Game_Init(void){
  for (uint8_t r = 0; r < GRID_ROWS; r++)
  for (uint8_t c = 0; c < GRID_COLS; c++)
  grid_matrix[r][c] = 0;

  M = SysTick->VAL;  // RNG implement
  respawnTray();
  //inits to 0
  holding = 0;
  holdSlot = 0;
  holdCol = 0;
  holdRow = 0;
  lastUpBtn = 0;
  lastDownBtn = 0;
  lastJoyX = 0;
  score = 0; 
  ST7735_DrawBitmap(0, 159, grid, 128, 160);
  drawTray();
  LED_Off(LED_MASK);
  LED_On(LED_SLOT0);
  drawScore();  
}
//called in game whlie loop, should return 1 if should return to MENU (back button held), 0 otherwise
static uint8_t Game_Tick(uint32_t sw, uint32_t jx, uint32_t jy){
  // back button must hold for ~1 second to exit
    static uint8_t backHoldCount = 0;
    if (sw & SWITCH_LEFT){
      backHoldCount++;
      if (backHoldCount >= 30){  // 30 ticks * 33ms = ~1 second
        backHoldCount = 0;
        holding = 0;
        return 1;
      }
    } 
    else{
      backHoldCount = 0;
    }

  // --------------------------------------------------------
  // WHEN NOT HOLDING A BLOCK, can navigate tray
  // ----------------------------------------------
  if (!holding){
    //left
    if (jx > 3000 && lastJoyX == 0){
      if (traySelection > 0) traySelection--;
      lastJoyX = 1;
      updateLEDs();
      drawTray();
    }
    else if (jx < 1000 && lastJoyX == 0){
      //right
      if (traySelection < 2) traySelection++;
      lastJoyX = 1;
      updateLEDs();
      drawTray();
    }
    else if (jx > 1500 && jx < 2500){
      lastJoyX = 0;
    }

    //UP button: pick up the selected block (if available)
    if ((sw & SWITCH_UP) && !lastUpBtn){
      lastUpBtn = 1;
      if (blockAvail[traySelection]){
        holding  = 1;
        holdSlot = traySelection;
        blockAvail[holdSlot] = 0; 
        holdCol = (GRID_COLS / 2) - (allBlockTypes[traySlotType[holdSlot]].cellCols / 2);
        holdRow = (GRID_ROWS / 2) - (allBlockTypes[traySlotType[holdSlot]].cellRows / 2);
        if (holdCol < 0) holdCol = 0;
        if (holdRow < 0) holdRow = 0;
        Block_Pickup();
        drawTray();// redraws tray with that slot now blank
        drawScore();
        drawHeldBlock(cellToPixX(holdCol), cellToPixY(holdRow), 0);
      }
    }
    else if (!(sw & SWITCH_UP)){
      lastUpBtn = 0;
    }

    // --------------------------------------------------------
    // IF HOLDING A BLOCK, move it around
    // --------------------------------------------
  }
  else{
    uint8_t moved = 0;
    int8_t  newCol = holdCol;
    int8_t  newRow = holdRow;
    uint8_t maxCol = GRID_COLS - allBlockTypes[traySlotType[holdSlot]].cellCols;
    uint8_t maxRow = GRID_ROWS - allBlockTypes[traySlotType[holdSlot]].cellRows;
    // x
    if (jx > 3000 && lastJoyX == 0){
      if (newCol > 0) newCol--;
      lastJoyX = 1; moved = 1;
    }
    else if (jx < 1000 && lastJoyX == 0){
      if (newCol < (int8_t)maxCol) newCol++;
      lastJoyX = 1; moved = 1;
    }
    else if (jx > 1500 && jx < 2500){
      lastJoyX = 0;
    }
    //y
    static uint8_t lastJoyY = 0;
    if (jy > 3000 && lastJoyY == 0){
      if (newRow > 0) newRow--;
      lastJoyY = 1; moved = 1;
    }
    else if (jy < 1000 && lastJoyY == 0){
      if (newRow < (int8_t)maxRow) newRow++;
      lastJoyY = 1; moved = 1;
    }
    else if (jy > 1500 && jy < 2500){
      lastJoyY = 0;
    }

    if (moved){
      ST7735_DrawBitmap(0, 159, grid, 128, 160);
      for (uint8_t r = 0; r < GRID_ROWS; r++){
        for (uint8_t c = 0; c < GRID_COLS; c++){
          if (grid_matrix[r][c]){
            uint16_t color = 0x001f;
            for (uint8_t py = 1; py < CELL_SIZE - 1; py++){
              for (uint8_t px = 1; px < CELL_SIZE - 1; px++){
                ST7735_DrawPixel(GRID_X0 + c * CELL_SIZE + px,
                GRID_Y0 + r * CELL_SIZE + py,
                color);
              }
            }
          }
        }
      }
      drawTray();
      holdCol = newCol;
      holdRow = newRow;
      drawHeldBlock(cellToPixX(holdCol), cellToPixY(holdRow), 0);
      drawScore();
    }

    // down to place block
    if ((sw & SWITCH_DOWN) && !lastDownBtn){
      lastDownBtn = 1;
      if (canPlace(holdSlot, holdCol, holdRow)){
        // valid placement!
        stampBlock(holdSlot, holdCol, holdRow);
        Block_Place();
        holding = 0;
        checkAndClearLines();
        // redraw game screen
        ST7735_DrawBitmap(0, 159, grid, 128, 160);
        // redraw placed blocks
        for (uint8_t r = 0; r < GRID_ROWS; r++){
          for (uint8_t c = 0; c < GRID_COLS; c++){
            if (grid_matrix[r][c]){
              uint16_t color = 0x001f;
              for (uint8_t py = 1; py < CELL_SIZE - 1; py++){
                for (uint8_t px = 1; px < CELL_SIZE - 1; px++){
                  ST7735_DrawPixel(GRID_X0 + c * CELL_SIZE + px,
                  GRID_Y0 + r * CELL_SIZE + py,
                  color);
                }
              }
            }
          }
        }
        drawTray();
        updateLEDs();
        drawScore();
        // respawn tray when all 3 blocks placed
        uint8_t allPlaced = (!blockAvail[0] && !blockAvail[1] && !blockAvail[2]);
        if (allPlaced){
          respawnTray();
          updateLEDs();
          drawTray();
        }
        // check game over after every placement (and after respawn)
        if (isGameOver()){
          showGameOver();
          //wait for the btn to restart
          while (!(sw_status & SWITCH_RIGHT)){}
          Game_Init();
          return 0;
        }
      }
      else{
        //invalid placement
        Block_Reject();
      }
    }
    else if (!(sw & SWITCH_DOWN)){
      lastDownBtn = 0;
    }

    //cancelling pickup if up btn while in hovering mode
    if ((sw & SWITCH_UP) && !lastUpBtn){
      lastUpBtn = 1;
      blockAvail[holdSlot] = 1; // restore to tray
      drawHeldBlock(cellToPixX(holdCol), cellToPixY(holdRow), 1);
      ST7735_DrawBitmap(0, 159, grid, 128, 160);
      // redraw placed cells
      for (uint8_t r = 0; r < GRID_ROWS; r++){
        for (uint8_t c = 0; c < GRID_COLS; c++){
          if (grid_matrix[r][c]){
            uint16_t color = 0x001f;
            for (uint8_t py = 1; py < CELL_SIZE - 1; py++){
              for (uint8_t px = 1; px < CELL_SIZE - 1; px++){
                ST7735_DrawPixel(GRID_X0 + c * CELL_SIZE + px,
                GRID_Y0 + r * CELL_SIZE + py,
                color);
              }
            }
          }
        }
      }
      holding = 0;
      drawTray();
      updateLEDs();
    }
    else if (!(sw & SWITCH_UP)){
      lastUpBtn = 0;
    }
  }

  return 0;
}

// ****note to ECE319K students****
// the data sheet says the ADC does not work when clock is 80 MHz
// however, the ADC seems to work on my boards at 80 MHz
// I suggest you try 80MHz, but if it doesn't work, switch to 40MHz
void PLL_Init(void){ // set phase lock loop (PLL)
//Clock_Init40MHz(); // run this line for 40MHz
Clock_Init80MHz(0);   // run this line for 80MHz
}

//SlidePot Sensor(1769,13); //my callibration for one pot

// games  engine runs at 30Hz
//ISR
void TIMG12_IRQHandler(void){uint32_t pos,msg;
if((TIMG12->CPU_INT.IIDX) == 1){ // this will acknowledge
GPIOB->DOUTTGL31_0 = GREEN; // toggle PB27 (minimally intrusive debugging)
GPIOB->DOUTTGL31_0 = GREEN; // toggle PB27 (minimally intrusive debugging)
// game engine goes here
// 1) sample joystick
JoyStick_In(&JoyX, &JoyY);
// 2) read input switches
sw_status = Switch_In();
// 3) move sprites
// 4) start sounds
// 5) set semaphore
// NO LCD OUTPUT IN INTERRUPT SERVICE ROUTINES
GPIOB->DOUTTGL31_0 = GREEN; // toggle PB27 (minimally intrusive debugging)
}
}
uint8_t TExaS_LaunchPadLogicPB27PB26(void){
  return (0x80|((GPIOB->DOUT31_0>>26)&0x03));
}
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
int main(void){ //main 5 final
  __disable_irq();
  PLL_Init();
  LaunchPad_Init();
  ST7735_InitPrintf(INITR_BLACKTAB); // INITR_REDTAB for AdaFruit, INITR_BLACKTAB for HiLetGo
  //initialize everything
  JoyStick_Init();
  Switch_Init(); // initialize switches
  LED_Init();    // initialize LED
  Sound_Init();  // initialize sound
  TExaS_Init(0,0,&TExaS_LaunchPadLogicPB27PB26); // PB27 and PB26
  // initialize interrupts on TimerG12 at 30 Hz
  TimerG12_IntArm(80000000/30,2);
  __enable_irq();

  //redefine state enum on local scope
  typedef enum { MENU, TUTORIAL, GAME } GameState_t;
  GameState_t state = MENU;

  uint32_t lang = 0;
  uint32_t menuSelection = 0;
  uint32_t lastJoy = 0;
  uint32_t lastBtn = 0;
  uint8_t dirty = 1;

  const char *menuPlay[]= {"Play","Jugar"};
  const char *menuTutorial[] = {"Tutorial", "Tutorial"};
  const char *menuLang[] = {"Language", "Idioma"};
  const char *tutorialText[] = {Tutorial_Text, Spn_Tutorial_Text};

  while (1){
    uint32_t sw = sw_status;
    uint32_t jx = JoyX;
    uint32_t jy = JoyY;

    // Menu
    if (state == MENU){
      // Joystick up/down navigates menu
      if (jy > 3000 && lastJoy == 0){
        if (menuSelection > 0) menuSelection--;
        lastJoy = 1; dirty = 1;
      }
      else if (jy < 1000 && lastJoy == 0){
        if (menuSelection < 2) menuSelection++;
        lastJoy = 1; dirty = 1;
      }
      else if (jy > 1500 && jy < 2500){
        lastJoy = 0;
      }
      // Right button selects
      if ((sw & SWITCH_RIGHT) && !lastBtn){
        lastBtn = 1;
        if (menuSelection == 0){
          state = GAME;
          Game_Init(); // initialize grid, LEDs, draw game screen
          dirty = 0;// Game_Init handles its own first draw
        }
        else if (menuSelection == 1){
          state = TUTORIAL;
          dirty = 1;
        }
        else if (menuSelection == 2){
          lang = (lang + 1) % 2;
          dirty = 1;
        }
      }
      else if (!(sw & SWITCH_RIGHT) && !(sw & SWITCH_LEFT)){
        lastBtn = 0;
      }

      //draw menu if dirty & we are  still in the MENU state
      if (dirty && state == MENU){
        dirty = 0;
        ST7735_DrawBitmap(0, 159, Home, 128, 160);
        uint16_t c0 = (menuSelection == 0) ? ST7735_YELLOW : ST7735_WHITE;
        uint16_t c1 = (menuSelection == 1) ? ST7735_YELLOW : ST7735_WHITE;
        uint16_t c2 = (menuSelection == 2) ? ST7735_YELLOW : ST7735_WHITE;
        ST7735_DrawString(4, 10, (char *)(menuSelection == 0 ? ">" : " "), c0);
        ST7735_DrawString(5, 10, (char *)menuPlay[lang], c0);
        ST7735_DrawString(4, 11, (char *)(menuSelection == 1 ? ">" : " "), c1);
        ST7735_DrawString(5, 11, (char *)menuTutorial[lang], c1);
        ST7735_DrawString(4, 12, (char *)(menuSelection == 2 ? ">" : " "), c2);
        ST7735_DrawString(5, 12, (char *)menuLang[lang], c2);
      }

      // TUTORIAL state
      // -------------------------------------
    }
    else if (state == TUTORIAL){
      // CRITICAL: Reset joystick if user lets go while in the tutorial
      // This fixes the joystick breaking when returning to the menu
      if (jy > 1500 && jy < 2500){
        lastJoy = 0;
      }

      //left btn as back 
      if ((sw & SWITCH_LEFT) && !lastBtn){
        lastBtn = 1;
        state = MENU;
        dirty = 1;
      }
      else if (!(sw & SWITCH_LEFT) && !(sw & SWITCH_RIGHT)){
        lastBtn = 0;
      }

      // Draw tutorial if dirty AND we are actually still in the TUTORIAL state
      if (dirty && state == TUTORIAL){
        dirty = 0;
        ST7735_FillScreen(ST7735_BLACK);
        ST7735_DrawFastHLine(0, 10, 128, ST7735_CYAN);
        ST7735_DrawString(3, 0, (char *)"TUTORIAL", ST7735_CYAN);
        ST7735_DrawFastHLine(0, 10, 128, ST7735_CYAN);
        ST7735_SetTextColor(ST7735_WHITE);
        ST7735_SetCursor(0, 2);
        ST7735_OutString((char *)tutorialText[lang]);
        ST7735_DrawString(0, 15, (char *)"< back", ST7735_WHITE);
      }
    }
    // GAME state
    // ---------------------------
    else if (state == GAME){
      // Game_Tick handles all input, drawing, LEDs.
      // Returns 1 if player pressed back -> return to menu.
      uint8_t goBack = Game_Tick(sw, jx, jy);
      if (goBack){
        state = MENU;
        LED_Off(LED_MASK);
        dirty = 1;  // menu needs redraw next iteration
      }
    }
    Clock_Delay1ms(33); // ~30 Hz main loop (ISR also runs at 30 Hz)
  }
}

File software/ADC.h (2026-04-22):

/*!
 * @defgroup ADC
 * @brief Analog to digital conversion
  <table>
<caption id="ADCpins">ADC pins on the MSPM0G3507</caption>
<tr><th>Pin  <th>ADC channel<th>Sensor
<tr><td>PA27 <td>ADC0 channel 0 <td>J1.8 also MKII light interrupt
<tr><td>PA26 <td>ADC0 channel 1 <td>J1.6 MKII microphone in
<tr><td>PA25 <td>ADC0 channel 2 <td>J1.2 MKII Joystick X
<tr><td>PA24 <td>ADC0 channel 3 <td>J3.27 ***free***
<tr><td>PB25 <td>ADC0 channel 4 <td>J19.7 (insert 0ohm R74, no U3 OPA2365)
<tr><td>PB24 <td>ADC0 channel 5 <td>J1.5 thermistor, also MKII joystick select button
<tr><td>PB20 <td>ADC0 channel 6 <td>J4.36 ***free***
<tr><td>PA22 <td>ADC0 channel 7 <td>J24 MKII Accelerometer Y

<tr><td>PA15 <td>ADC1 channel 0 <td>J3.30 (also DACout)
<tr><td>PA16 <td>ADC1 channel 1 <td>J3.29 ***free***
<tr><td>PA17 <td>ADC1 channel 2 <td>J3.28 ***free***
<tr><td>PA18 <td>ADC1 channel 3 <td>J3.26 MKII Joystick Y
<tr><td>PB17 <td>ADC1 channel 4 <td>J2.18 ***free***
<tr><td>PB18 <td>ADC1 channel 5 <td>J3.25 MKII Accelerometer Z
<tr><td>PB19 <td>ADC1 channel 6 <td>J3.23 MKII Accelerometer X
<tr><td>PA21 <td>ADC1 channel 7 <td>J17.8 (insert R20, remove R3)

</table>
 * @{*/
/**
 * @file      ADC.h
 * @brief     Initialize 12-bit ADC0 and/or ADC1
 * @details   ADC input, software trigger, 12-bit conversion<br>
 * The ADC allows two possible references: 2.5V or 3.3V.<br>
 * The internal 2.5V reference is lower noise, but limits the range to 0 to 2.5V.<br>
 * The other possibility is to use the analog voltage supply at 3.3V,
 * making the ADC range 0 to 3.3V. In this driver, the 3.3V range is selected.
 * There are several configurations (each with initialization and a
 * read ADC with software trigger, busy-wait function)<br>

 * @version   ECE319K v1.0
 * @author    Daniel Valvano and Jonathan Valvano
 * @copyright Copyright 2023 by Jonathan W. Valvano, valvano@mail.utexas.edu,
 * @warning   AS-IS
 * @note      For more information see  http://users.ece.utexas.edu/~valvano/
 * @date      August 13, 2023
 <table>
<caption id="ADCpins2">ADC pins on the MSPM0G3507</caption>
<tr><th>Pin  <th>ADC channel<th>Sensor
<tr><td>PA27 <td>ADC0 channel 0 <td>J1.8 also MKII light interrupt
<tr><td>PA26 <td>ADC0 channel 1 <td>J1.6 MKII microphone in
<tr><td>PA25 <td>ADC0 channel 2 <td>J1.2 MKII Joystick X
<tr><td>PA24 <td>ADC0 channel 3 <td>J3.27 ***free***
<tr><td>PB25 <td>ADC0 channel 4 <td>J19.7 (insert 0ohm R74, no U3 OPA2365)
<tr><td>PB24 <td>ADC0 channel 5 <td>J1.5 also MKII joystick select button
<tr><td>PB20 <td>ADC0 channel 6 <td>J4.36 ***free***
<tr><td>PA22 <td>ADC0 channel 7 <td>J24 MKII Accelerometer Y

<tr><td>PA15 <td>ADC1 channel 0 <td>J3.30 (also DACout)
<tr><td>PA16 <td>ADC1 channel 1 <td>J3.29 ***free***
<tr><td>PA17 <td>ADC1 channel 2 <td>J3.28 ***free***
<tr><td>PA18 <td>ADC1 channel 3 <td>J3.26 MKII Joystick Y
<tr><td>PB17 <td>ADC1 channel 4 <td>J2.18 ***free***
<tr><td>PB18 <td>ADC1 channel 5 <td>J3.25 MKII Accelerometer Z
<tr><td>PB19 <td>ADC1 channel 6 <td>J3.23 MKII Accelerometer X
<tr><td>PA21 <td>ADC1 channel 7 <td>J17.8 (insert R20, remove R3)

</table>
  ****note to students****<br>
  the data sheet says the ADC does not work when clock is 80 MHz
  however, the ADC seems to work on my boards at 80 MHz
  I suggest you try 80MHz, but if it doesn't work, switch to 40MHz
  ******************************************************************************/



//#ifndef __ADC_H__
//#define __ADC_H__
#include <ti/devices/msp/msp.h>
#include <stdint.h>
/**
 * \brief using ADCVREF_INT means choose internal 2.5V reference for accuracy
 */
#define ADCVREF_INT  0x200
/**
 * \brief using ADCVREF_EXT means choose external reference not tested
 */ 
#define ADCVREF_EXT  0x100
/**
 * \brief using ADCVREF_VDDA means choose power line 3.3V reference for 0 to 3.3V range
 */
#define ADCVREF_VDDA 0x000

/**
 * Initialize 12-bit ADC0 in software-triggered mode to take
 * measurements when the associated function is called.
 * One channel is to be measured
 * @param channel is the 0 to 7
 * @param reference is ADCVREF_INT, ADCVREF_EXT, ADCVREF_VDDA
 * @return none 
 * @brief  Initialize 12-bit ADC0
 */
void ADC0_Init(uint32_t channel, uint32_t reference);

/**
 * Trigger a single ADC0 measurement,
 * wait for it to complete, and return the 12-bit result
 * as 0 to 4095.
 * The ADC input voltage range is 0 to 3.3V.
 * Busy-wait synchronization used.
 * @param none
 * @return 12-bit result
 * @note  Assumes ADC0_Init has been called.
 * @brief  Trigger ADC measurement and wait for result.
 */
uint32_t ADC0_In(void);

/**
 * Initialize 12-bit ADC1 in software-triggered mode to take
 * measurements when the associated function is called.
 * One channel is to be measured
 * @param channel is the 0 to 7
 * @param reference is ADCVREF_INT, ADCVREF_EXT, ADCVREF_VDDA
 * @return none 
 * @brief  Initialize 12-bit ADC0
 */
void ADC1_Init(uint32_t channel, uint32_t reference);

/**
 * Trigger a single ADC1 measurement,
 * wait for it to complete, and return the 12-bit result
 * as 0 to 4095.
 * The ADC input voltage range is 0 to 3.3V.
 * Busy-wait synchronization used.
 * @param none
 * @return 12-bit result
 * @note  Assumes ADC1_Init has been called.
 * @brief  Trigger ADC measurement and wait for result.
 */
uint32_t ADC1_In(void);

/**
 * Initialize 12-bit ADC0 or ADC1 in software-triggered mode to take
 * measurements when the associated function is called.
 * One channel is to be measured
 * @param adc12 is ADC0 or ADC1
 * @param channel is the 0 to 7
 * @param reference is ADCVREF_INT, ADCVREF_EXT, ADCVREF_VDDA
 * @return none
 * @brief  Initialize 12-bit ADC0
 */
void ADC_Init(ADC12_Regs *adc12, uint32_t channel, uint32_t reference);

/**
 * Trigger a single ADC0 or ADC1 measurement,
 * wait for it to complete, and return the 12-bit result
 * as 0 to 4095.
 * The ADC input voltage range is 0 to 3.3V.
 * Busy-wait synchronization used.
 * @param adc12 is ADC0 or ADC1
 * @return 12-bit result
 * @note  Assumes ADC_Init has been called.
 * @brief  Trigger ADC measurement and wait for result.
 */
uint32_t ADC_In(ADC12_Regs *adc12);

/**
 * Initialize 12-bit ADC0 or ADC1 in software-triggered mode to take
 * measurements when the associated function is called.
 * Two channels are to be measured
 * @param adc12 is ADC0 or ADC1
 * @param channel1 is the 0 to 7
 * @param channel2 is the 0 to 7
 * @param reference is ADCVREF_INT, ADCVREF_EXT, ADCVREF_VDDA
 * @return none 
 * @brief  Initialize 12-bit ADC for two channels
 */
void ADC_InitDual(ADC12_Regs *adc12, uint32_t channel1, uint32_t channel2, uint32_t reference);
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

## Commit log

2026-04-02 Hardware files
    [Copy of Pins_Assignments.xlsx, Lab 9 Pin Assignments.xlsx, PCB Camp Pins_Assignments.xlsx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]
2026-04-16 default software file added
    [ColorConvert5-6-5.xlsx, trig.xlsx]
2026-04-22 updated readME
    Expanded the README to include detailed game mechanics, system architecture, joystick and button functionality, sound implementation, graphics handling, game logic, LED indicators, and language suppo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
2026-04-22 added files for software
    [model.step]
